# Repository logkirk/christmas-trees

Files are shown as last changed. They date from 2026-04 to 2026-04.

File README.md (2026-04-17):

# christmas-trees

Simple light-up Christmas tree ornaments.

This was a practice project for learning Altium Designer and practicing PCB design, board bring-up, and debugging.

## Design

The double-sided board uses the front silkscreen layer to make the LEDs appear like a strand of lights on a Christmas tree. When two CR2032 coin cell batteries are inserted on the back and the switch is turned on, the lights flash sequentially.

The design uses a simple LM555 timer circuit to increment an octal counter. Each output of the counter controls a single LED.

## Files

```
.
├── altium       original Altium Designer files
├── kicad        converted KiCad files
├── images       schematic, board view, and PCB images
└── README.md
```

## Project Images

### Schematic
<details>
<summary>Click to expand</summary>
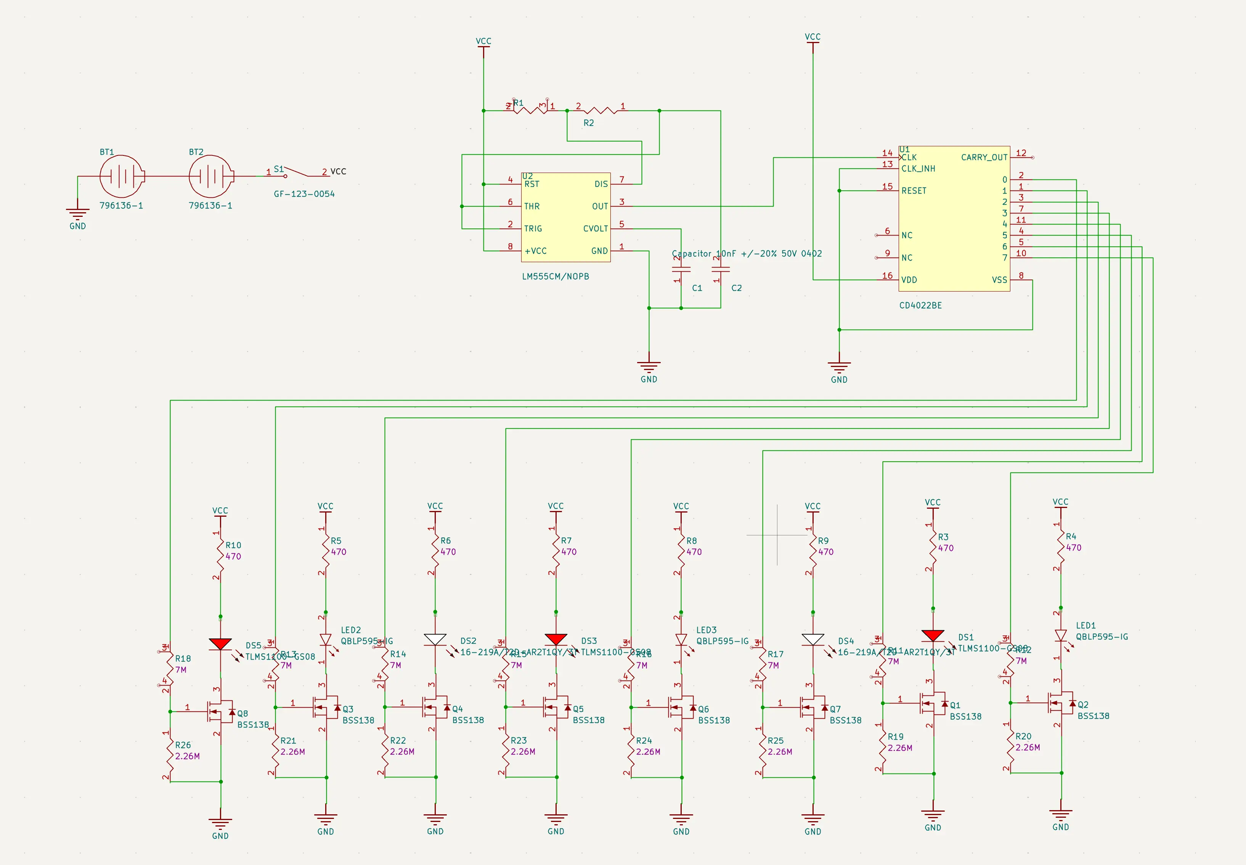
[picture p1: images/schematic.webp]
Schematic

</details>

### Board Views
<details>
<summary>Click to expand</summary>
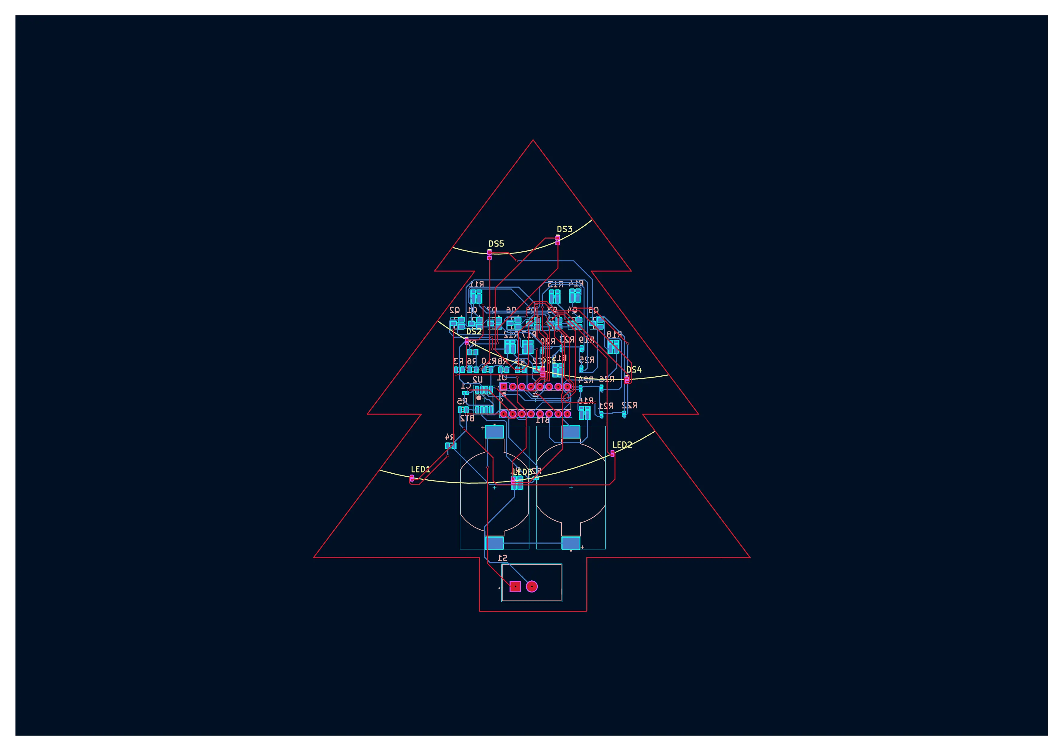
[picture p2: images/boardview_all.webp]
Board view, all

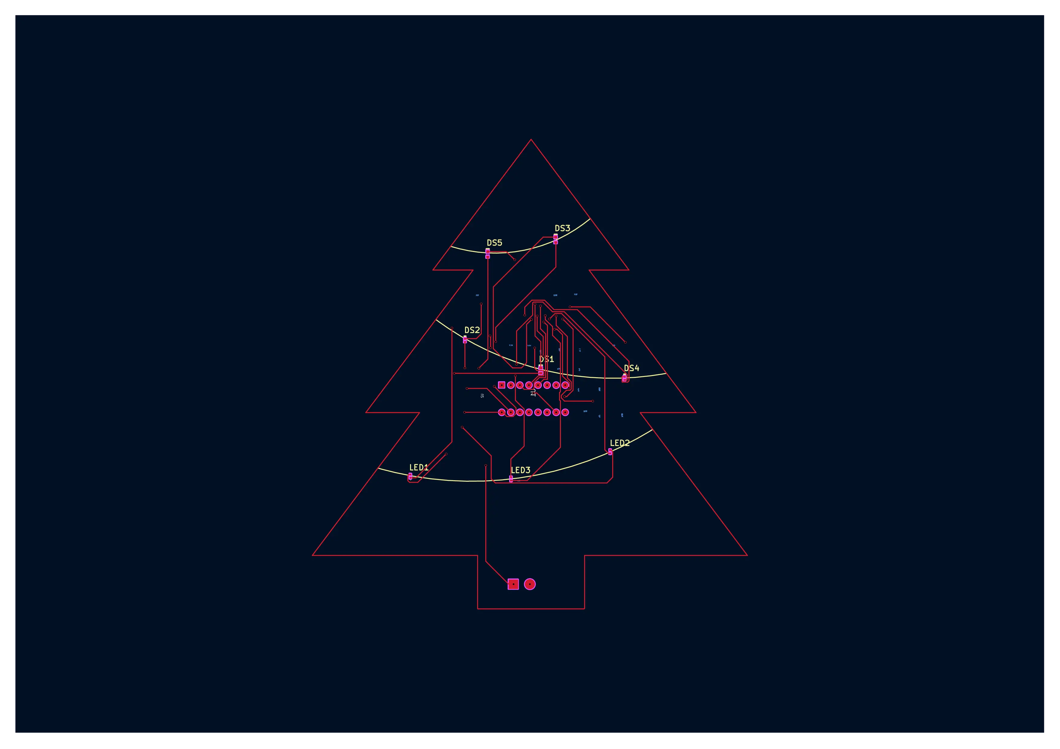
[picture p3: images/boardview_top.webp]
Board view, top

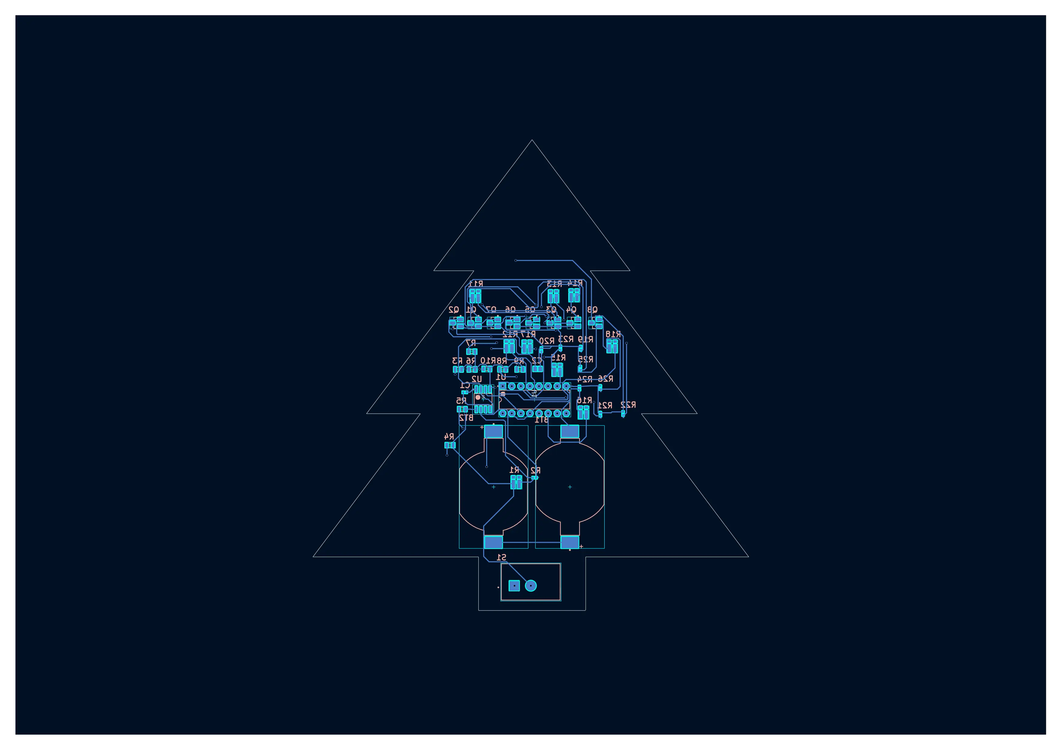
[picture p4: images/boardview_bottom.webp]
Board view, bottom

</details>

### Bare Board

Bare board fresh from JLCPCB. They came back looking clean.

<details>
<summary>Click to expand</summary>
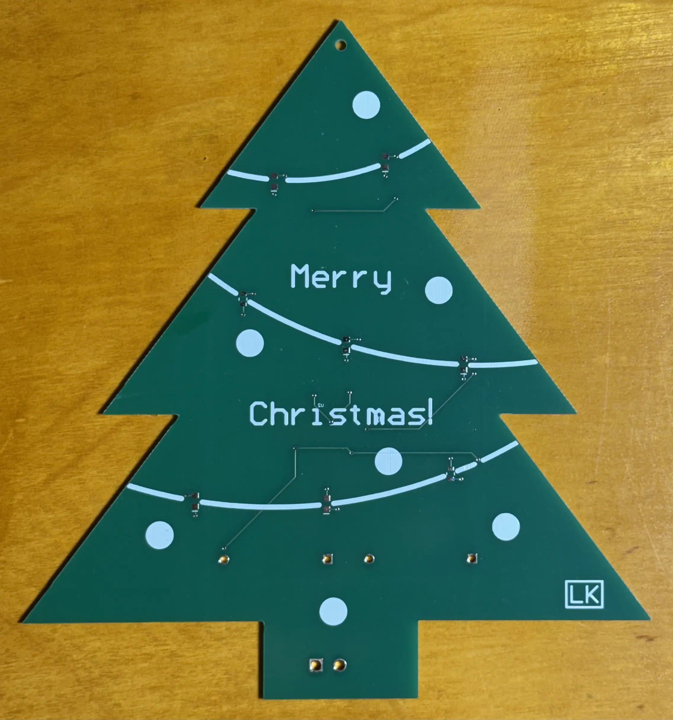
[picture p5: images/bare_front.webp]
Bare board, front

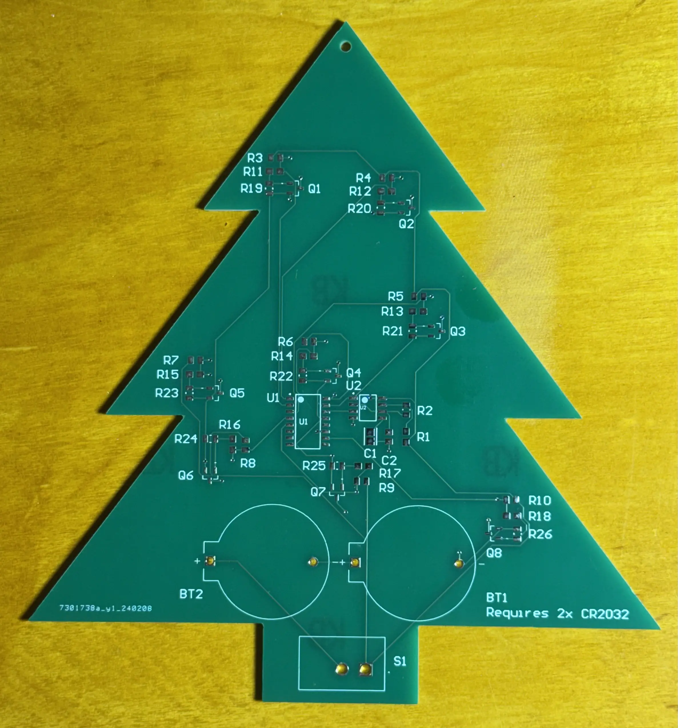
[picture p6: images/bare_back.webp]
Bare board, back

</details>

### Modded Board

Of course the first run had some bugs. I was able to get it working after a bit of troubleshooting and some board modifications.

<details>
<summary>Click to expand</summary>
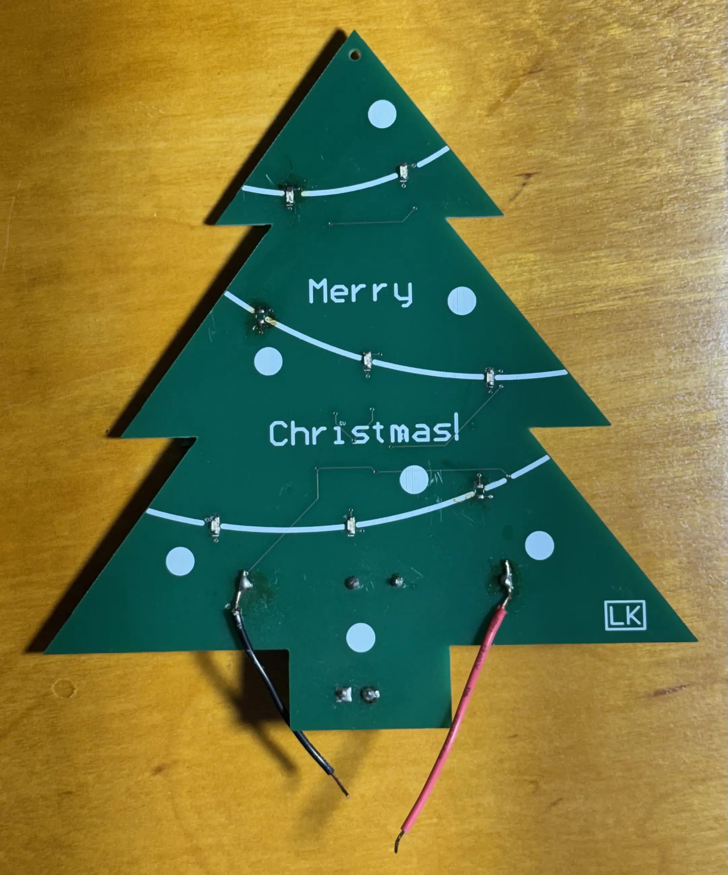
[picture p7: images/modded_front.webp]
Modded board, front

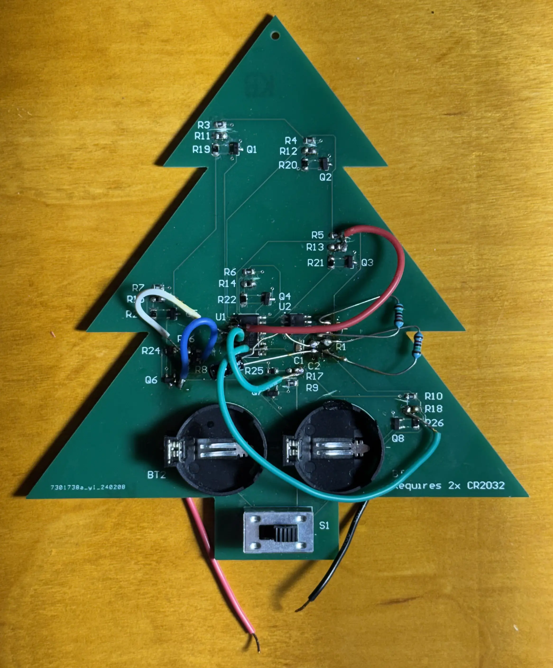
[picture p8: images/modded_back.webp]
Modded board, back

</details>

## Lessons Learned

- Double check trace widths before ordering. I used the default trace width, which led to the traces being thinner than expected. It didn't cause any electrical issues, but the traces could've been wider for the same cost.

## Next Steps

- Translate indentified design issues back into schematic and layout
- Order another run of boards

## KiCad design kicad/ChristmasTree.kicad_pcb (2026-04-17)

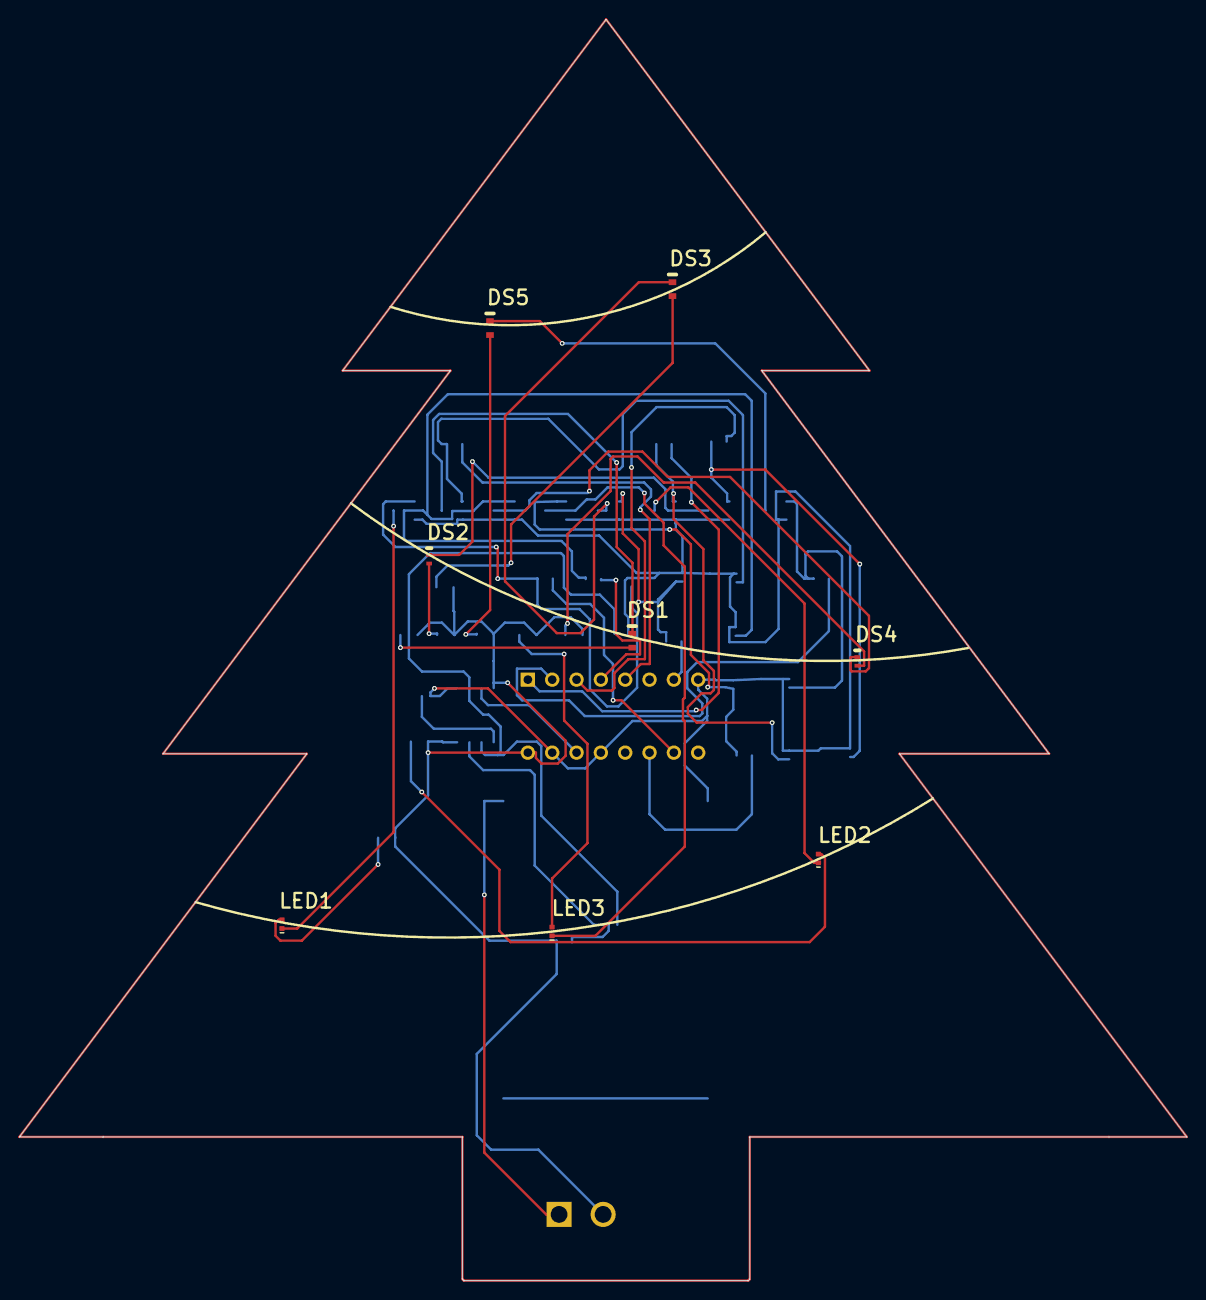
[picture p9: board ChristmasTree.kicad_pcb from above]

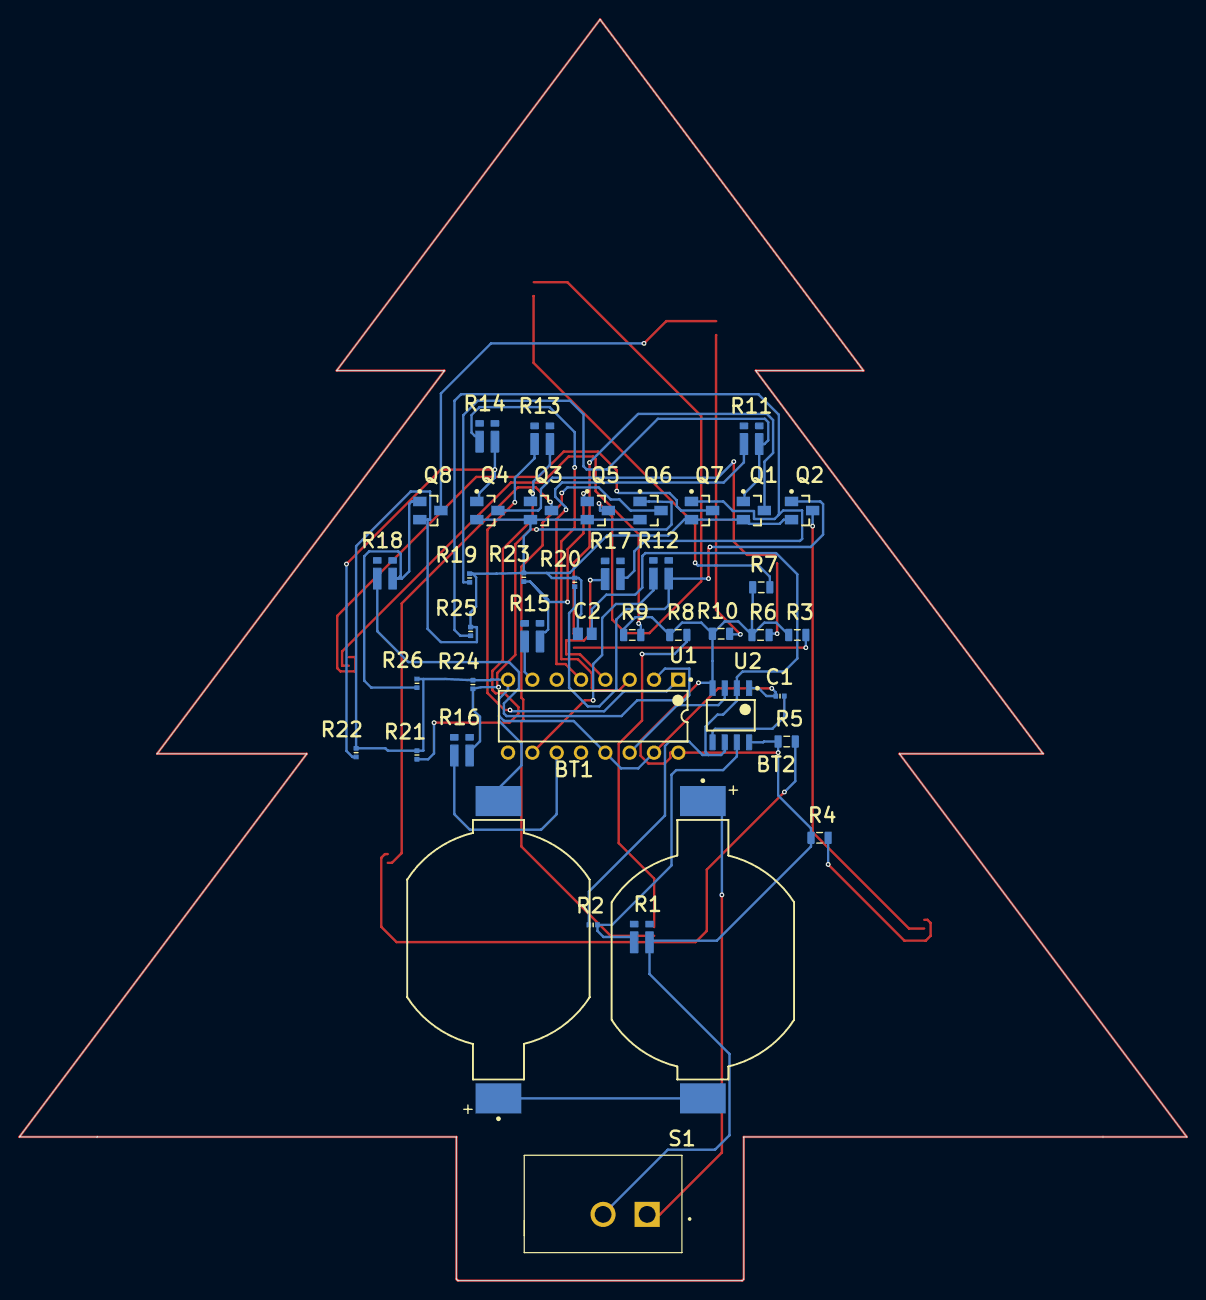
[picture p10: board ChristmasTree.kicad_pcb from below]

Board: 2 copper layers, 121.9 x 131.7 mm, 49 parts (41 on the bottom side), 40 nets.

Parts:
BT1, BT2: 796136-1; TECO-796136-1_V
C1: Capacitor 10nF +/-20% 50V 0402; CAPC0402(1005)60_L
C2: Capacitor 100 nF +/-10% 50 V 0805; CAPC2013X95X50LL10T25
DS1, DS3, DS5: TLMS1100-GS08; VISH-TLMX1100_V
DS2, DS4: 16-219A/T2D-AR2T1QY/3T; EVRL-0402-2_V
LED1, LED2, LED3: QBLP595-IG; QTB-QBLP595_V
Q1, Q2, Q3, Q4, Q5, Q6, Q7, Q8: BSS138; FAIR-SOT23-3_V
R1, R11, R12, R13, R14, R15, R16, R17, R18: KRL3216T4A-M-R007-F-T1; SUSUMU-3216T4A
R2: Resistor 1M +/-1 % 0402 63 mW; RESC0402(1005)_L
R3, R4, R5, R6, R7, R8, R9, R10: Resistor 470R +/-5% 0805 125 mW; RESC0805(2012)_L
R19, R20, R21, R22, R23, R24, R25, R26: 2D26MR2F; RESC0402(1005)_L
S1: GF-123-0054; SW_GF-123-0054
U1: CD4022BE; N0016A
U2: LM555CM/NOPB; D0008A_M

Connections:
GND: BT1.2, C1.1, C2.1, Q1.2, Q2.2, Q3.2, Q4.2, Q5.2, Q6.2, Q7.2, Q8.2, R19.2, R20.2, R21.2, R22.2, R23.2, R24.2, R25.2, R26.2, U1.8, U1.13, U1.15, U2.1
NetBT1_1: BT1.1, BT2.2
NetBT2_1: BT2.1, S1.1
NetC1_2: C1.2, U2.5
NetC2_2: C2.2, R2.1, U2.2, U2.6
NetDS1_1: DS1.1, R3.2
NetDS1_2: DS1.2, Q1.3
NetDS2_1: DS2.1, R6.2
NetDS2_2: DS2.2, Q4.3
NetDS3_1: DS3.1, R7.2
NetDS3_2: DS3.2, Q5.3
NetDS4_1: DS4.1, R9.2
NetDS4_2: DS4.2, Q7.3
NetDS5_1: DS5.1, R10.2
NetDS5_2: DS5.2, Q8.3
NetLED1_1: LED1.1, Q2.3
NetLED1_2: LED1.2, R4.2
NetLED2_1: LED2.1, Q3.3
NetLED2_2: LED2.2, R5.2
NetLED3_1: LED3.1, Q6.3
NetLED3_2: LED3.2, R8.2
NetQ1_1: Q1.1, R11.2, R19.1
NetQ2_1: Q2.1, R12.2, R20.1
NetQ3_1: Q3.1, R13.2, R21.1
NetQ4_1: Q4.1, R14.2, R22.1
NetQ5_1: Q5.1, R15.2, R23.1
NetQ6_1: Q6.1, R16.2, R24.1
NetQ7_1: Q7.1, R17.2, R25.1
NetQ8_1: Q8.1, R18.2, R26.1
NetR1_1: R1.1, R2.2, U2.7
NetR11_1: R11.1, U1.5
NetR12_1: R12.1, U1.10
NetR13_1: R13.1, U1.1
NetR14_1: R14.1, U1.3
NetR15_1: R15.1, U1.7
NetR16_1: R16.1, U1.11
NetR17_1: R17.1, U1.4
NetR18_1: R18.1, U1.2
NetU1_14: U1.14, U2.3
VCC: R1.2, R3.1, R4.1, R5.1, R6.1, R7.1, R8.1, R9.1, R10.1, S1.2, U1.16, U2.4, U2.8
